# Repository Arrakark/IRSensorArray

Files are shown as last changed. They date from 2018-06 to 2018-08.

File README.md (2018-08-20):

# IR Sensor Array

An infra-red sensor array for detecting lines and small objects up to 15cm away.

## PCB Description

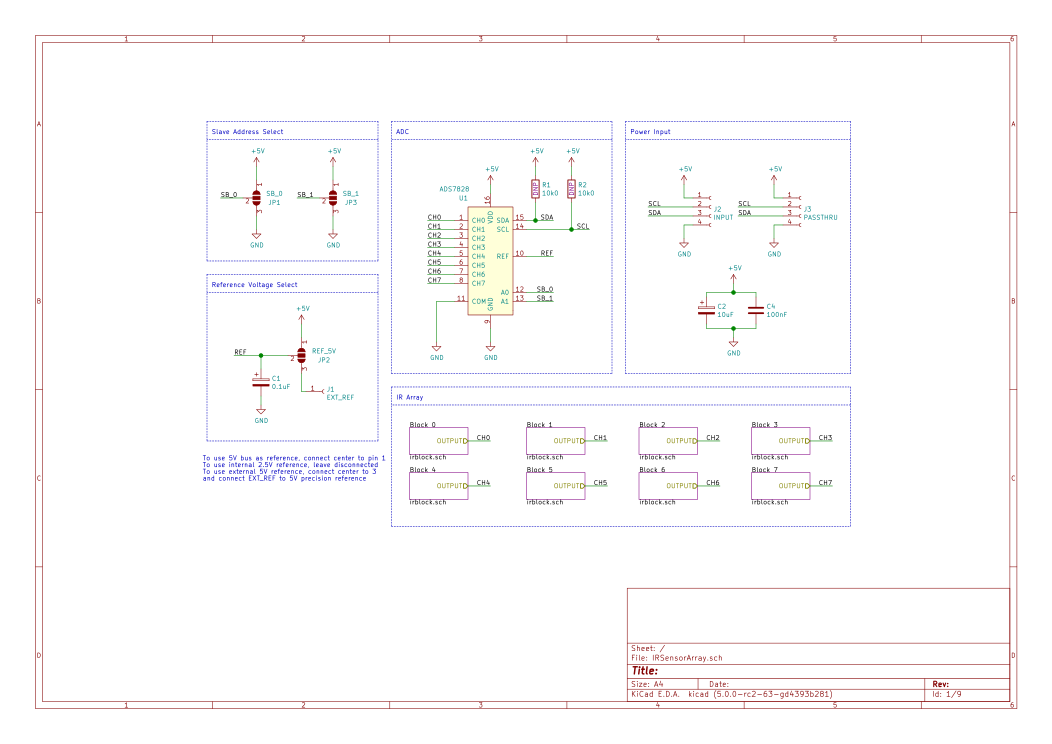
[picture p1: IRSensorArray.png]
Schematic


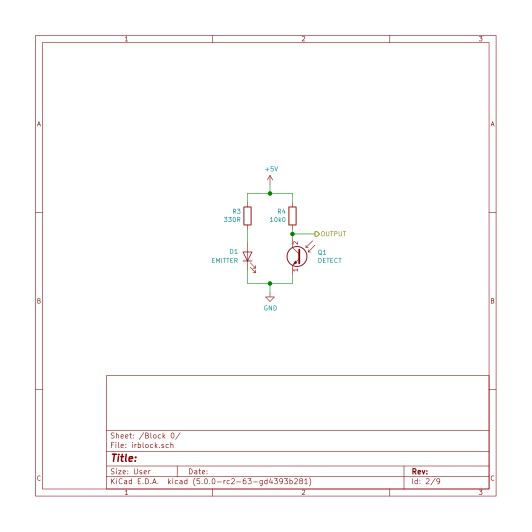
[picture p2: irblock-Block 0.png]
IR Block


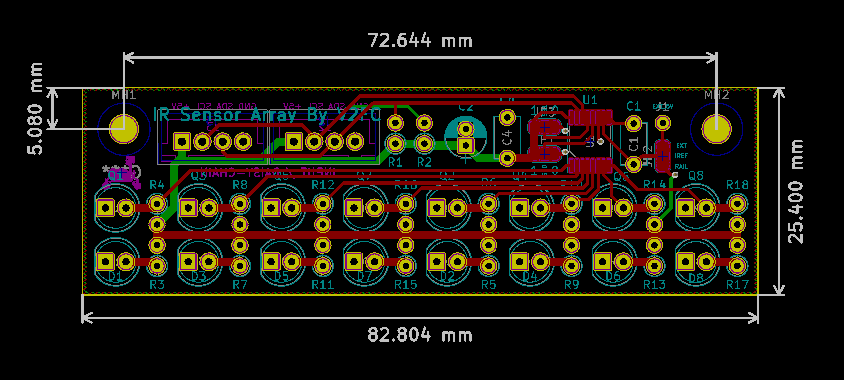
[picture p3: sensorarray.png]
PCB


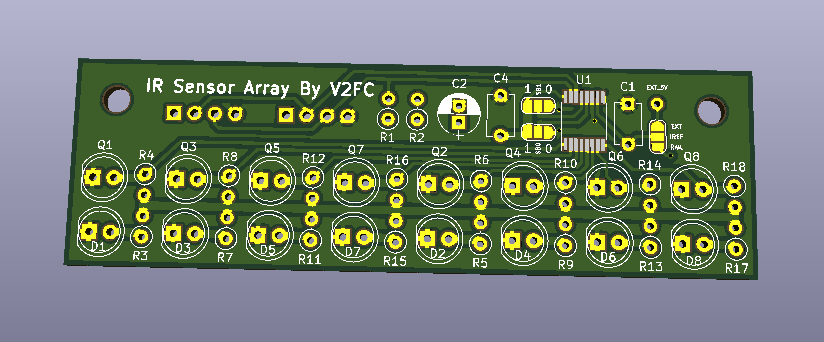
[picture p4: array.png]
3d view


### Specs

* 3.3V - 6V input voltage
* Can be used with I2C fast mode using ~2k pullups (try 10k first)
* Can detect lines with high precision and speed
* Can detect objects and surfaces up to 15cm away
* Uses 4-pin JST-XH headers for power and data
* Power and data be daisychained

This project was created using KiCad 5 RC2. Use it to open and edit this design.

### BOM

| | | | | | |  |  | 
|---|---|---|---|---|---|--|--|
| "Id" | "Designator" | "Package" | "Quantity" | "Designation" | "Supplier and ref" |  |  | 
| 1 | "MH2,MH1" | "MountingHole_3.2mm_M3" | 2 | "MountingHole_3.2mm_M3" | |  |  | 
| 2 | "C1" | "C_Disc_D5.1mm_W3.2mm_P5.00mm" | 1 | "0.1uF" | |  |  | 
| 3 | "C2" | "CP_Radial_D5.0mm_P2.00mm" | 1 | "10uF" | |  |  | 
| 4 | "C4" | "C_Disc_D5.1mm_W3.2mm_P5.00mm" | 1 | "100nF" | |  |  | 
| 5 | "D1,D2,D3,D4,D5,D6,D7,D8" | "LED_D5.0mm" | 8 | "EMITTER" | |  |  | 
| 6 | "J1" | "Measurement_Point_Round-TH_Small" | 1 | "EXT_REF" | |  |  | 
| 7 | "Q1,Q2,Q3,Q5,Q6,Q7,Q8,Q4" | "LED_D5.0mm" | 8 | "QSD124" | |  |  | 
| 8 | "R1,R2,R4,R6,R8,R10,R12,R14,R16,R18" | "R_Axial_DIN0207_L6.3mm_D2.5mm_P2.54mm_Vertical" | 10 | "10k0" | |  |  | 
| 9 | "R3,R5,R7,R9,R11,R13,R15,R17" | "R_Axial_DIN0207_L6.3mm_D2.5mm_P2.54mm_Vertical" | 8 | "330R" | |  |  | 
| 10 | "U1" | "TSSOP-16_4.4x5mm_Pitch0.65mm" | 1 | "ADS7828" | |  |  | 
| 11 | "J2" | "JST_XH_B04B-XH-A_04x2.50mm_Straight" | 1 | "INPUT" | |  |  | 
| 12 | "J3" | "JST_XH_B04B-XH-A_04x2.50mm_Straight" | 1 | "PASSTHRU" | |  |  | 
| 13 | "JP1" | "SolderJumper-3_P1.3mm_Open_RoundedPad1.0x1.5mm_NumberLabels" | 1 | "SB_0" | |  |  | 
| 14 | "JP2" | "SolderJumper-3_P1.3mm_Open_RoundedPad1.0x1.5mm_NumberLabels" | 1 | "REF_5V" | |  |  | 
| 15 | "JP3" | "SolderJumper-3_P1.3mm_Open_RoundedPad1.0x1.5mm_NumberLabels" | 1 | "SB_1" | |  |  | 
| 16 | "G***" | "rover" | 1 | "LOGO" | |  |  | 

## Installing

Install the sensor array using two M3 screws and standoffs.

## Signal Control

Use the library included with this repo to read the values of the sensors. 

Use the following code to create a sensor array object:
```
SensorArray array1(lookup_table, I2C ID);
```
See the header file for an example.

## License

This project is licensed under the MIT License - see the [LICENSE.md](https://github.com/Arrakark/IRSensorArray/blob/master/LICENSE) file for details

## Acknowledgments

* Special thanks to the V2FC robot team!

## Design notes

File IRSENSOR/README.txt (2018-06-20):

This library was copied from the following repo from deskwizard: https://github.com/deskwizard/Arduino_DAC_ADC_libraries

Special thanks!

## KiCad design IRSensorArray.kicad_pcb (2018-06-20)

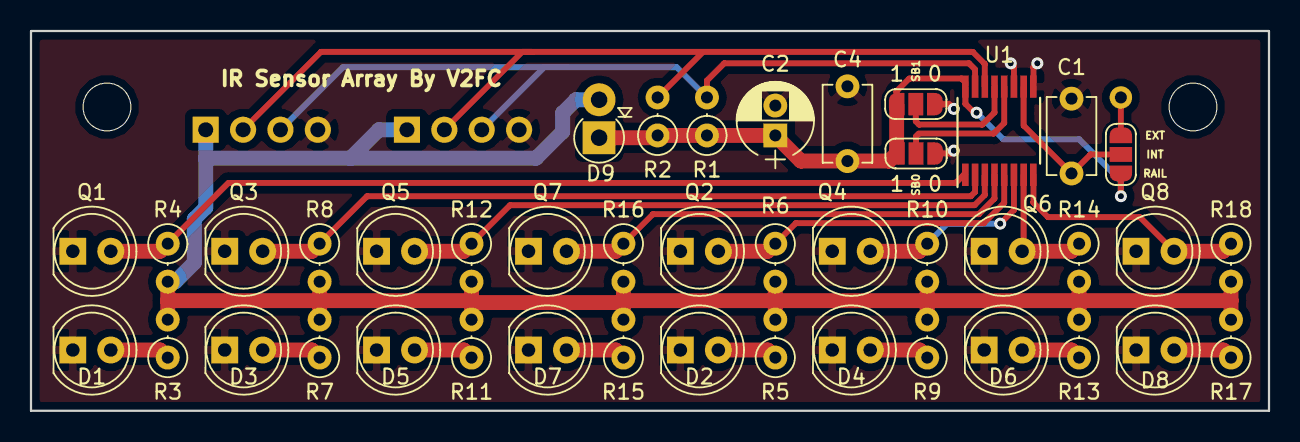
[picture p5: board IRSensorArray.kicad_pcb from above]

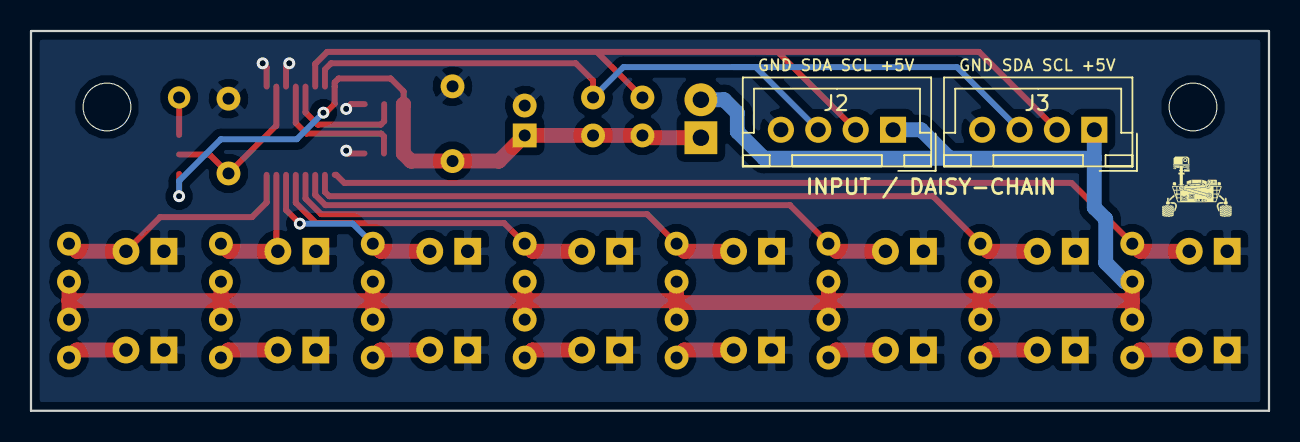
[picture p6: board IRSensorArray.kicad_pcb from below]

Board: 2 copper layers, 82.8 x 25.4 mm, 47 parts (2 on the bottom side), 25 nets.

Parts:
C1: 0.1uF; C_Disc_D5.1mm_W3.2mm_P5.00mm
C2: 10uF; CP_Radial_D5.0mm_P2.00mm
C4: 100nF; C_Disc_D5.1mm_W3.2mm_P5.00mm
D1, D2, D3, D4, D5, D6, D7, D8: HSDL-4420; LED_D5.0mm
D9: 1N4007; D_DO-41_SOD81_P2.54mm_Vertical_AnodeUp
J1: EXT_REF; Measurement_Point_Round-TH_Small
J2: INPUT; JST_XH_B04B-XH-A_04x2.50mm_Straight
J3: PASSTHRU; JST_XH_B04B-XH-A_04x2.50mm_Straight
JP1: SB_0; SolderJumper-3_P1.3mm_Open_RoundedPad1.0x1.5mm_NumberLabels
JP2: REF_5V; SolderJumper-3_P1.3mm_Open_RoundedPad1.0x1.5mm_NumberLabels
JP3: SB_1; SolderJumper-3_P1.3mm_Open_RoundedPad1.0x1.5mm_NumberLabels
MH1, MH2: MountingHole_3.2mm_M3
Q1, Q2, Q3, Q4, Q5, Q6, Q7, Q8: QSD124; LED_D5.0mm
R1, R2, R4, R6, R8, R10, R12, R14, R16, R18: 10k0; R_Axial_DIN0207_L6.3mm_D2.5mm_P2.54mm_Vertical
R3, R5, R7, R9, R11, R13, R15, R17: 330R; R_Axial_DIN0207_L6.3mm_D2.5mm_P2.54mm_Vertical
U1: ADS7828; TSSOP-16_4.4x5mm_Pitch0.65mm

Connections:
+5V: C2.1, C4.1, D9.1, JP1.1, JP2.1, JP3.1, R1.1, R2.1, U1.16
/CH0: Q1.2, R4.1, U1.1
/CH1: Q3.2, R8.1, U1.2
/CH2: Q5.2, R12.1, U1.3
/CH3: Q7.2, R16.1, U1.4
/CH4: Q2.2, R6.1, U1.5
/CH5: Q4.2, R10.1, U1.6
/CH6: Q6.2, R14.1, U1.7
/CH7: Q8.2, R18.1, U1.8
/REF: C1.1, JP2.2, U1.10
/SB_0: JP1.2, U1.12
/SB_1: JP3.2, U1.13
/SCL: J2.2, J3.2, R2.2, U1.14
/SDA: J2.3, J3.3, R1.2, U1.15
GND: C1.2, C2.2, C4.2, D1.1, D2.1, D3.1, D4.1, D5.1, D6.1, D7.1, D8.1, J2.4, J3.4, JP1.3, JP3.3, Q1.1, Q2.1, Q3.1, Q4.1, Q5.1, Q6.1, Q7.1, Q8.1, U1.9, U1.11
unnamed: D1.2, R3.1
unnamed: D2.2, R5.1
unnamed: D3.2, R7.1
unnamed: D4.2, R9.1
unnamed: D5.2, R11.1
unnamed: D6.2, R13.1
unnamed: D7.2, R15.1
unnamed: D8.2, R17.1
unnamed: J1.1, JP2.3
VCC: D9.2, J2.1, J3.1, R3.2, R4.2, R5.2, R6.2, R7.2, R8.2, R9.2, R10.2, R11.2, R12.2, R13.2, R14.2, R15.2, R16.2, R17.2, R18.2

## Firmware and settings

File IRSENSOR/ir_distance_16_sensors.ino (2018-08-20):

//Line following and Ewok Grabbing with 16 IR sensors on Blue Pill Board

#include <Wire.h>
#include <ADS7828.h>
#include <Arduino.h>
#include <IRDIST.h>

#define S_LEN_UNIT 8

#define ROW 20
#define COL 9
#define DIST_COL 0

//---------------------------------------------

//thresholds
double std_w_avg = 8.5; //standard weighted average for 16 IR sensors
int cut_off_dist = 30;

//sensor arrays (for 1 sensor unit: left most, idx = 0; right most, idx = 7)

int s_val_1[S_LEN_UNIT];
int s_val_2[S_LEN_UNIT];

//array of distances

int dist_raw_1[S_LEN_UNIT];
int dist_calib_1[S_LEN_UNIT];

int dist_raw_2[S_LEN_UNIT];
int dist_calib_2[S_LEN_UNIT];

//data file arrays
const PROGMEM int data_1[ROW][COL] = { {1, 131, 125, 134, 132, 129, 133, 135, 140},
  {3, 140, 134, 145, 143, 140, 143, 149, 150},
  {5, 150, 145, 155, 151, 147, 152, 157, 159},
  {7, 160, 156, 163, 159, 156, 160, 165, 168},
  {10, 174, 169, 176, 170, 166, 171, 176, 179},
  {12, 182, 177, 183, 176, 172, 177, 184, 187},
  {15, 196, 188, 196, 188, 182, 188, 195, 198},
  {17, 207, 195, 205, 196, 189, 195, 204, 206},
  {20, 227, 207, 222, 210, 200, 206, 218, 219},
  {23, 373, 229, 277, 243, 220, 225, 255, 251},
  {25, 417, 237, 337, 268, 229, 235, 281, 267},
  {28, 629, 305, 613, 527, 291, 301, 551, 489},
  {30, 768, 429, 764, 703, 445, 459, 745, 685},
  {33, 856, 540, 900, 860, 601, 617, 883, 818},
  {36, 960, 659, 1038, 1014, 757, 779, 1038, 971},
  {39, 1029, 736, 1131, 1122, 866, 891, 1142, 1077},
  {42, 1081, 785, 1198, 1202, 947, 976, 1223, 1155},
  {44, 1097, 809, 1227, 1236, 981, 1015, 1255, 1188},
  {46, 1092, 810, 1233, 1247, 991, 1026, 1258, 1192},
  {50, 1156, 889, 1314, 1337, 1081, 1123, 1351, 1291}
};

int data_3[ROW][COL] = { {1, 139, 136, 144, 132, 133, 134, 138, 145},
  {3, 145, 144, 152, 140, 140, 141, 145, 151},
  {5, 156, 154, 161, 150, 149, 152, 155, 161},
  {7, 166, 163, 172, 158, 158, 161, 165, 172},
  {10, 185, 177, 189, 170, 170, 174, 180, 187},
  {12, 200, 188, 206, 179, 179, 184, 192, 199},
  {15, 238, 204, 253, 190, 191, 198, 211, 218},
  {17, 462, 225, 604, 203, 203, 213, 239, 248},
  {20, 842, 369, 11085, 231, 231, 255, 476, 481},
  {23, 1106, 662, 1416, 364, 358, 510, 804, 757},
  {25, 1217, 792, 1563, 537, 531, 679, 950, 880},
  {28, 1399, 992, 1767, 786, 784, 923, 1165, 1070},
  {30, 1487, 1095, 1871, 925, 927, 1062, 1289, 1179},
  {33, 1569, 1189, 1973, 1059, 1064, 1192, 1398, 1273},
  {36, 1720, 1344, 2102, 1224, 1229, 1351, 1549, 1414},
  {39, 1786, 1417, 2175, 1323, 1329, 1448, 1638, 1496},
  {42, 1870, 1504, 2253, 1424, 1429, 1548, 1730, 1584},
  {44, 1968, 1603, 2337, 1528, 1537, 1648, 1827, 1679},
  {46, 2080, 1715, 2434, 1651, 1661, 1770, 1947, 1795},
  {50, 2200, 1839, 2531, 1779, 1788, 1893, 2068, 1917}
};

const PROGMEM int data_4[ROW][COL] = { {1, 137, 126, 124, 120, 126, 124, 136, 136},
  {3, 152, 138, 137, 131, 140, 135, 151, 146},
  {5, 169, 148, 148, 142, 151, 146, 161, 161},
  {7, 184, 158, 155, 150, 159, 154, 171, 171},
  {10, 243, 177, 169, 161, 172, 167, 192, 188},
  {12, 702, 195, 180, 170, 182, 177, 217, 203},
  {15, 1259, 273, 200, 184, 199, 193, 595, 254},
  {17, 1612, 728, 241, 199, 223, 212, 1091, 605},
  {20, 1878, 1139, 627, 231, 424, 312, 1525, 1005},
  {23, 2099, 1447, 1017, 449, 800, 690, 1829, 1306},
  {25, 2182, 1587, 1214, 668, 1002, 909, 1992, 1466},
  {28, 2354, 1818, 1505, 985, 1287, 1213, 2225, 1711},
  {30, 2442, 1944, 1673, 1167, 1452, 1392, 2355, 1849},
  {33, 2504, 2039, 1803, 1312, 1586, 1538, 2461, 1967},
  {36, 2611, 2173, 1969, 1490, 1747, 1712, 2594, 2121},
  {39, 2694, 2283, 2107, 1638, 1880, 1856, 2704, 2254},
  {42, 2752, 2358, 2205, 1746, 1979, 1965, 2786, 2354},
  {44, 2792, 2379, 2234, 1778, 2007, 1996, 2801, 2373},
  {46, 2761, 2384, 2246, 1794, 2002, 2016, 2816, 2393},
  {50, 2805, 2440, 2320, 1874, 2096, 2098, 2877, 2469}
};

int data_5[ROW][COL] = { {1, 137, 127, 124, 128, 131, 131, 138, 145},
  {3, 144, 135, 133, 136, 140, 137, 147, 153},
  {5, 157, 145, 145, 144, 149, 147, 154, 164},
  {7, 169, 154, 153, 152, 156, 154, 161, 172},
  {10, 196, 171, 167, 165, 169, 167, 176, 187},
  {12, 244, 182, 176, 173, 178, 177, 186, 200},
  {15, 875, 204, 192, 189, 195, 194, 207, 238},
  {17, 1227, 236, 210, 204, 216, 212, 236, 455},
  {20, 1568, 495, 271, 243, 319, 280, 507, 864},
  {23, 1745, 746, 541, 473, 676, 629, 849, 1138},
  {25, 1866, 906, 732, 689, 895, 855, 1051, 1304},
  {28, 2013, 1102, 967, 953, 1162, 1132, 1310, 1525},
  {30, 2126, 1239, 1129, 1129, 1340, 1313, 1482, 1677},
  {33, 2248, 1392, 1307, 1325, 1536, 1512, 1678, 1850},
  {36, 2329, 1496, 1436, 1467, 1678, 1660, 1816, 1972},
  {39, 2126, 1607, 1558, 1598, 1806, 790, 1942, 2084},
  {42, 2473, 1670, 1637, 1685, 1894, 1882, 2036, 2172},
  {44, 2520, 1724, 1700, 1752, 1961, 1951, 2102, 2233},
  {46, 2559, 1771, 1752, 1809, 2019, 2011, 2162, 2291},
  {50, 2616, 1843, 1836, 1898, 2107, 2100, 2254, 2378}
};

//constructors
ADS7828 adc1(0x48); //chip id 1 and 5
ADS7828 adc2(0x4B);

//functions
void read_sensor_values(int arr[S_LEN_UNIT], ADS7828 adc);
void printArray (int arr[], int lengthsize);
int* arr_rel_dist(int arr[S_LEN_UNIT], int arr_new_dist[S_LEN_UNIT], int thres);
double w_avg(int arr[S_LEN_UNIT], int horz_shift);
double avg(int arr[S_LEN_UNIT]);
int min_value(int arr[S_LEN_UNIT]);
int max_value(int arr[S_LEN_UNIT]);
double mean_range(int arr[S_LEN_UNIT]);

//--------------------------------------------------------

void setup() {
  Wire.begin();

  Serial.begin(115200);
}

void loop() {

  //  IRDIST sensor_1(dist_raw_1, data_1, s_val_1);
  //  read_sensor_values(s_val_1, adc1);
  //  int *dist_1_pid = sensor_1.readDist(dist_raw_1, s_val_1, data_1);
  //  int *dist_1_ewok = arr_rel_dist(dist_1_pid, dist_calib_1, cut_off_dist);
  //
  //  printArray(dist_1_pid, S_LEN_UNIT);
  //  printArray(dist_1_ewok, S_LEN_UNIT);
  //  Serial.print("Ewok Centering 1: ");
  //  Serial.println(w_avg(dist_1_ewok, 0)); //for ewok and edge detection

  //  IRDIST sensor_2(dist_raw_2, data_5, s_val_2);
  //  read_sensor_values(s_val_2, adc2);
  //  int *dist_2_pid = sensor_2.readDist(dist_raw_2, s_val_2, data_4);
  //  int *dist_2_ewok = arr_rel_dist(dist_raw_2, dist_calib_2, cut_off_dist);
  //
  //  printArray(dist_2_pid, S_LEN_UNIT);
  //  printArray(dist_2_ewok, S_LEN_UNIT);
  //  Serial.print("Ewok Centering 2: ");
  //  Serial.println(w_avg(dist_2_ewok, 8)); //for ewok and edge detection
  //
  //  Serial.println((w_avg(dist_2_ewok, 8) + w_avg(dist_1_ewok, 0)) / 2);
  
//  int i, j;
//  for (i = 0; i < ROW; i++) {
//    for (j = 0; j < COL; j++) {
//      Serial.print(pgm_read_word_near(&(data_1[i][j])));
//      Serial.print(" ");
//    }
//    Serial.println();
//  }

  Serial.println();
}

//--------------------------------------------------------
void printArray (int arr[], int lengthsize) {

  int i;
  for (i = 0; i < lengthsize; i ++) {
    Serial.print(arr[i]);
    Serial.print(" ");
  }

  Serial.println();
}

void read_sensor_values(int arr[S_LEN_UNIT], ADS7828 adc) {

  int i;

  for (i = 0; i < S_LEN_UNIT; i ++)
    arr[i] = adc.read(i, SD);
}

//----------------

int* arr_rel_dist(int arr[S_LEN_UNIT], int arr_new_dist[S_LEN_UNIT], int thres) {

  int i;

  for (i = 0; i < S_LEN_UNIT; i ++)
    arr_new_dist[i] = thres - arr[i];

  return arr_new_dist;
}

//----------------

double w_avg(int arr[S_LEN_UNIT], int horz_shift) {

  int i;
  float weighted_sum = 0;
  float sum = 0;

  for (i = 0; i < S_LEN_UNIT; i++) {

    weighted_sum += (i + 1 + horz_shift) * arr[i]; //1st arr horz_shift = 0; 2nd arr horz_shift = 8
    sum += arr[i];
  }

  return weighted_sum / sum;
}

//----------------

double avg(int arr[S_LEN_UNIT]) {

  int i;
  double sum = 0;

  for (i = 0; i < S_LEN_UNIT; i++)
    sum += arr[i];

  return sum / S_LEN_UNIT;
}

//----------------

int min_value(int arr[S_LEN_UNIT]) {

  int i;
  int min_val = arr[0];

  for (i = 1; i < S_LEN_UNIT; i++) {

    if (arr[i] < min_val)
      min_val = arr[i];
  }

  return min_val;
}

//----------------

int max_value(int arr[S_LEN_UNIT]) {

  int i;
  int max_val = arr[0];

  for (i = 1; i < S_LEN_UNIT; i++) {

    if (arr[i] > max_val)
      max_val = arr[i];
  }

  return max_val;
}

//----------------

double mean_range(int arr[S_LEN_UNIT]) {

  return ((double)(max_value(arr)) - min_value(arr)) / 2;
}

//----------------

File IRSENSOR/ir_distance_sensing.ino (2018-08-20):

//Line follower with 8 IR sensors on Blue Pill Board

#include<stdio.h>
#include <Wire.h>
#include <ADS7828.h>
ADS7828 adc(0x48);


#define SENSE_NUM 8

#define ROW 20
#define COL 9
#define DIST_COL 0

//---------------------------------------------

//sensor values -> left most, idx = 0; right most, idx = 7
unsigned int s_value[SENSE_NUM] = {0,0,0,0,0,0,0,0};

//array of distances                                  
int dist_arr[SENSE_NUM];

//make new data file array for testing *******
int data_arr[ROW][COL] = { {1,122,118,123,120,116,122,120,127},
                           {3,137,128,138,137,136,139,143,145},
                           {5,147,140,151,147,144,150,155,157},
                           {7,158,151,159,156,152,158,163,167},
                           {10,177,168,175,169,165,171,177,182},
                           {12,196,181,188,179,174,180,189,193},
                           {15,331,204,215,198,189,197,513,219},
                           {17,686,230,262,217,201,211,240,250},
                           {20,1110,533,764,441,240,275,576,603},
                           {23,1377,859,1147,876,520,655,940,940},
                           {25,1524,1307,1355,1115,761,896,1143,1128},
                           {28,1688,1235,1591,1400,1057,1193,1406,1385},
                           {30,1811,1382,1752,1587,1251,1387,1580,1559},
                           {33,1841,1430,1827,1688,1363,1499,1673,1652},
                           {36,1967,1567,1970,1850,1531,1669,1833,1809},
                           {39,2062,1675,2085,1984,1670,1812,1966,1944},
                           {42,2151,1771,2183,2094,1783,1927,2077,2058},
                           {44,2195,1819,2233,2157,1847,1990,2140,2123},
                           {46,2244,1871,2283,2211,1908,2051,2202,2187},
                           {50,2342,1971,2382,2321,2020,2168,2318,2303} };

//functions
void read_sensor_values(void);
void printArray (int arr[], int lengthsize);
int* calculate_distance(int arr[SENSE_NUM],int sensor[SENSE_NUM],int data[ROW][COL]);
//some function that returns 2D array from file

//--------------------------------------------------------
void setup() {

  Serial.begin(9600);
  
  adc.init(INT);
}

void loop() {
  
  read_sensor_values();
  //printArray(s_value,SENSE_NUM);
  //Serial.println();
  int *dist_arr_pointer = calculate_distance(dist_arr,s_value,data_arr);
  //printArray(dist_arr_pointer,SENSE_NUM);
  
}

//--------------------------------------------------------

void read_sensor_values() {

  int i;
  
  for(i = 0; i < SENSE_NUM; i ++){
    s_value[i] = adc.read(i,SD);
  }
}

void printArray (int arr[], int lengthsize){

  int i;
  for(i = 0; i < lengthsize; i ++){
    Serial.print(arr[i]);
    Serial.print(" ");
  }

  Serial.println();
}

int* calculate_distance(int arr[SENSE_NUM],int sensor[SENSE_NUM],int data[ROW][COL]) {

  int ind = 0; //indices in data array
  int flag = 0; //boolean used for calculating distance
  int distance = 0;

  int i,j;

  //calculating distances measured in sensor array
  for(i = 0; i < SENSE_NUM; i ++) {

    //find corresponding indices in data array
    for(j = 0; j < ROW; j ++) {

      if(data[j][i+1] >= sensor[i]){
        
        ind = j;
        flag = 1;
        break;
      }
    }

    //calculate distance
    
    if(!flag) //if sensor measured distance is greater than values in data array, let sensor distance = 100
      arr[i] = 100;

    else {

      //calculating slope and y-intercpet : y = mx + b
      int x2 = data[ind][i+1];
      int y2 = data[ind][DIST_COL];

      Serial.print("x2: ");
      Serial.print(x2);
      Serial.print(" ");
      Serial.print("y2: ");
      Serial.print(y2);
      Serial.println();

      int x1 = data[ind-1][i+1];
      int y1 = data[ind-1][DIST_COL];

      Serial.print("x1: ");
      Serial.print(x1);
      Serial.print(" ");
      Serial.print("y1: ");
      Serial.print(y1);
      Serial.println();

      float m = ((float)(y2 - y1)) / (x2 - x1);
      float b = y2 - m * x2;

      float ans = m * sensor[i] + b;
      arr[i] = (int)(m * sensor[i] + b);

      Serial.print("sensor");
      Serial.print(i);
      Serial.print(": ");
      Serial.print(sensor[i]);
      Serial.print(" ");
      Serial.print("distance: ");
      Serial.print(arr[i]);
      Serial.print(" m: ");
      Serial.print(m);
      Serial.print(" b: ");
      Serial.print(b);
      Serial.print(" ans: ");
      Serial.print(ans);
      Serial.println();
      Serial.println();
    }
  }


  
//  arr[0] = 1;
//  arr[1] = 2;
//  arr[2] = 3;
//  arr[3] = 4;
//  arr[4] = 5;
//  arr[5] = 6;
//  arr[6] = 7;
//  arr[7] = 8;

  return arr;
}

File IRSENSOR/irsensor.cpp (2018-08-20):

/*
 *  IR Sensor Library
 *  How to use:
 *  Create new irsensor object:
 *      irsensor main_sensor = irsensor(0x49, lookup_table);
 *      the 0x49 is the address for the sensor (see sensor inventory in gdrive)
 *      the lookup_table is a calibration table for the sensor.
 *      See the example ir_distance_sensing.ino
 *      More calibration data is availible on gdrive
 *  Enable wire library:
 *      Wire.begin();
 *  Get new data from the sensor:  
 *      main_sensor.update();
 *  Acccess the methods of the sensor:
 *      main_sensor.max_position(); //returns the integer position of the max distance
 *      main_sensor.adc_readings[x]; //returns the x-positioned adc reading
 *      main_sensor.distance_readings[x] //returns the distance that a certain ir sensor sees
 *  
 *  TODO:
 *      currently the max # of sensors is 4 on each I2C line
 *      we will need 2 I2C lines to support 5 sensors
 *      need to implement selection of I2C bus
 */

#include "irsensor.h"

//create new irsensor array
irsensor::irsensor(unsigned char _adress, int _lookup_table[ROW][COL]) : adc(_adress)
{
    //adc.init(); do not call this function; call it in setup
    lookup_table = _lookup_table;
    SENSOR_COUNT = 8;
}

//default const do not use
irsensor::irsensor() : adc()
{
}

//get new readings from the sensor
void irsensor::update()
{
    // Serial.println("Updating ir sensor readings......");
    for (int x = 0; x < SENSOR_COUNT; x++)
    {
        adc_readings[x] = adc.read(x, SD);
    }
    // Serial.println("Starting get distance");
    get_distance();
}

//returns the position (0-7) of the maximum value
int irsensor::max_position()
{
    float max_value = MIN_VALUE;
    int max_position = 0;
    for (int x = 0; x < SENSOR_COUNT; x++)
    {
        if (distance_readings[x] > max_value)
        {
            max_value = distance_readings[x];
            max_position = x;
        }
    }
    return max_position;
}

//returns the position (0-7) of the minimum value
int irsensor::min_position()
{
    float min_value = MAX_VALUE;
    int min_position = 0;
    for (int x = 0; x < SENSOR_COUNT; x++)
    {
        if (distance_readings[x] < min_value)
        {
            min_value = distance_readings[x];
            min_position = x;
        }
    }
    return min_position;
}

//returns the max distance measured (MIN_VALUE-MAX_VALUE) in cm
float irsensor::max_distance()
{
    float max = MIN_VALUE;
    for (int x = 0; x < SENSOR_COUNT; x++)
    {
        if (distance_readings[x] > max)
        {
            max = distance_readings[x];
        }
    }
    return max;
}

//returns the min distance measured (MIN_VALUE-MAX_VALUE) in cm
float irsensor::min_distance()
{
    float min = MAX_VALUE;
    for (int x = 0; x < SENSOR_COUNT; x++)
    {
        if (distance_readings[x] < min)
        {
            min = distance_readings[x];
        }
    }
    return min;
}

//returns the weighted mean of values; to be used w/line following
float irsensor::weighted_mean()
{
    float t_sum = 0;
    float b_sum = 0;

    for (int x = 0; x < SENSOR_COUNT; x++)
    {
        t_sum = t_sum + distance_readings[x] * (x + 1);
        b_sum = b_sum + distance_readings[x];
    }

    if (b_sum > 0.1)
    {
        return t_sum / b_sum;
    }
    return 4.5;
}

//returns the inverse weighted mean; this means it takes the difference from the max value
//and uses that to compute the weighted mean
//to be used with ewok detection
float irsensor::inverse_weighted_mean()
{
    float t_sum = 0;
    float b_sum = 0;
    for (int x = 0; x < SENSOR_COUNT; x++)
    {
        t_sum = t_sum + (MAX_VALUE - distance_readings[x]) * (x + 1);
        b_sum = b_sum + (MAX_VALUE - distance_readings[x]);
    }
    if (b_sum > 0.1)
    {
        return t_sum / b_sum;
    }
    return 4.5;
}

//returns the mean (average)
//can be used for detecting cliffs
float irsensor::mean()
{
    float t_sum = 0;
    for (int x = 0; x < SENSOR_COUNT; x++)
    {
        t_sum += distance_readings[x];
    }
    return t_sum / SENSOR_COUNT;
}

void irsensor::info()
{
    update();
    for (int i = 0; i < 8; i++)
    {
        Serial.print(distance_readings[i]);
        Serial.print(" ");
    }
    Serial.println();
}

//private function for calculating the distance from the raw values
void irsensor::get_distance()
{
    int ind;  //indices in data array
    int flag; //boolean used for calculating distance

    int i, j;

    //calculating distances measured in sensor array
    for (i = 0; i < SENSOR_COUNT; i++)
    {

        flag = 0;
        ind = 0;

        //find corresponding indices in data array
        for (j = 0; j < ROW; j++)
        {
            if (lookup_table[j][i + 1] >= adc_readings[i])
            {
                ind = j;
                flag = 1;
                break;
            }
        }

        //calculate distance

        if (!flag)
        {
            //if sensor measured distance is greater than values in data array, let sensor distance = 100
            distance_readings[i] = MAX_VALUE;
        }

        else
        {
            if (ind > 0 && i > -1 && ind < ROW && i < 8)
            {
                //calculating slope and y-intercpet : y = mx + b
                int x2 = lookup_table[ind][i + 1];

                int y2 = lookup_table[ind][0];

                int x1 = lookup_table[ind - 1][i + 1];
                int y1 = lookup_table[ind - 1][0];
                if (x2 - x1 == 0)
                {
                    return;
                }

                float m = ((float)(y2 - y1)) / (x2 - x1);
                float b = y2 - m * x2;

                distance_readings[i] = (int)(m * adc_readings[i] + b);

                //set negative distances to zero
                if (distance_readings[i] < MIN_VALUE)
                    distance_readings[i] = MIN_VALUE;
                else if (distance_readings[i] > MAX_VALUE)
                    distance_readings[i] = MAX_VALUE;
            }

            else
            {
                distance_readings[i] = MIN_VALUE;
            }
        }
    }
}

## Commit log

2018-06-14 Started schematic, leaving rest
    [IRSensorArray.kicad_pcb, IRSensorArray.sch]
2018-06-19 Connected jumpers and ADC
    [IRSensorArray.sch]
2018-06-19 Added sensor array
    [IRSensorArray.sch, irblock.sch]
2018-06-19 Started PCB
    [IRSensorArray.sch, irblock.sch]
2018-06-19 Changed triangle solder bridges to semi-circle
    [IRSensorArray.kicad_pcb, IRSensorArray.sch, irblock.sch]
2018-06-19 Added mounting holes and some fixes
    [IRSensorArray.kicad_pcb]
2018-06-19 Started PCB layout
    [IRSensorArray.kicad_pcb, irblock.sch]
2018-06-20 First draft finished!
    [IRSensorArray.kicad_pcb, IRSensorArray.sch, irblock.sch]
2018-06-20 Added images
    [IRSensorArray.kicad_pcb, IRSensorArray.sch, irblock.sch]
2018-06-20 Added library for sensor
    [IRSensorArray-B.Cu.gbr, IRSensorArray-B.Mask.gbr, IRSensorArray-B.Paste.gbr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]
2018-06-20 Added reverse voltage diode
    [IRSensorArray.kicad_pcb, IRSensorArray.sch, _saved_IRSensorArray.sch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]
2018-06-20 Added new gerber files
    [IRSensorArray-B.Cu.gbr, IRSensorArray-B.Mask.gbr, IRSensorArray-B.Paste.gbr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]
2018-06-20 Final edit
    [IRSensorArray-B.Cu.gbr, IRSensorArray-B.Mask.gbr, IRSensorArray-B.Paste.gbr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]
